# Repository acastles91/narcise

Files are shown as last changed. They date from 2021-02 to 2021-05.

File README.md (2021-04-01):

# Installation instructions

1. Download [Visual Studio Code](https://code.visualstudio.com/) and once that is done, install [PlatformIO](https://docs.platformio.org/en/latest/integration/ide/vscode.html#installation).
2. Open a terminal window and install *numpy*, a python library, by running the following command in the terminal:
`pip3 install numpy`
3. Clone this repository in a folder that you can remember, by typing the following command into the terminal:
`git clone https://github.com/acastles91/narcise/`
	* Navigate through folders using the command `cd`
4. In **Visual Studio Code** go to *File > Open Folder* and open the folder *narciseFromScratch* inside the *narcise* directory that you just cloned. This is where you will compile the code that will go into the microcontroller.
5. Navigate to the *narcise* folder with the file browser. Inside of it you will find a directory called *scriptGenerator*. Open the file *script* with **TextEdit**.
6. Edit the script. Each line represents a keyframe, which you define by first defining the *Timestamp* with the format *hh:mm:ss:fff*, where fff represents fractions of a second in milliseconds. After that comes the value of opacity of each layer as a percentage, with 100 being transparent and 0 being totally opaque. It is important that you keep this format consistent throughout the whole file. Make sure that you leave **no extra whitespace at the end of the file*
7. After saving the script, go back to *Visual Studio Code*, with the folder *narciseFromScratch* opened. Go to the terminal and type:
`cd ../scriptGenerator`
`python3 scriptGenerator.py 1 200 7`

	The argument `1` means that the script will be looped, `200` is the refresh rate (the bigger the value the slower and more "flickery" the piece will look) and `7` is a parameter that relates to the difference between minimal and maximal value. Play around with this last parameter to see differences in the response time of the dimming.

8. After the script is generated, connect the microcontroller to the computer using a USB cable capable of transfering data and upload the program.

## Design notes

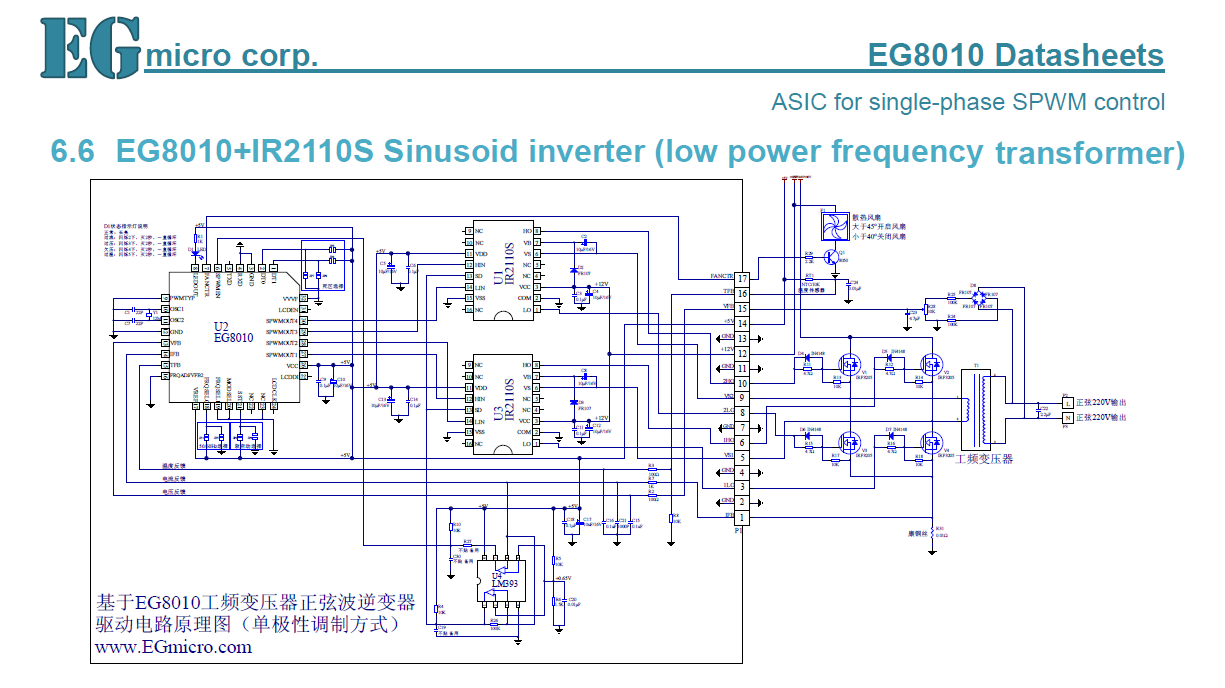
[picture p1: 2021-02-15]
EGS002-TechBuilder/Schematic, PCB Files & Datasheet/Schematics/Schematic.png

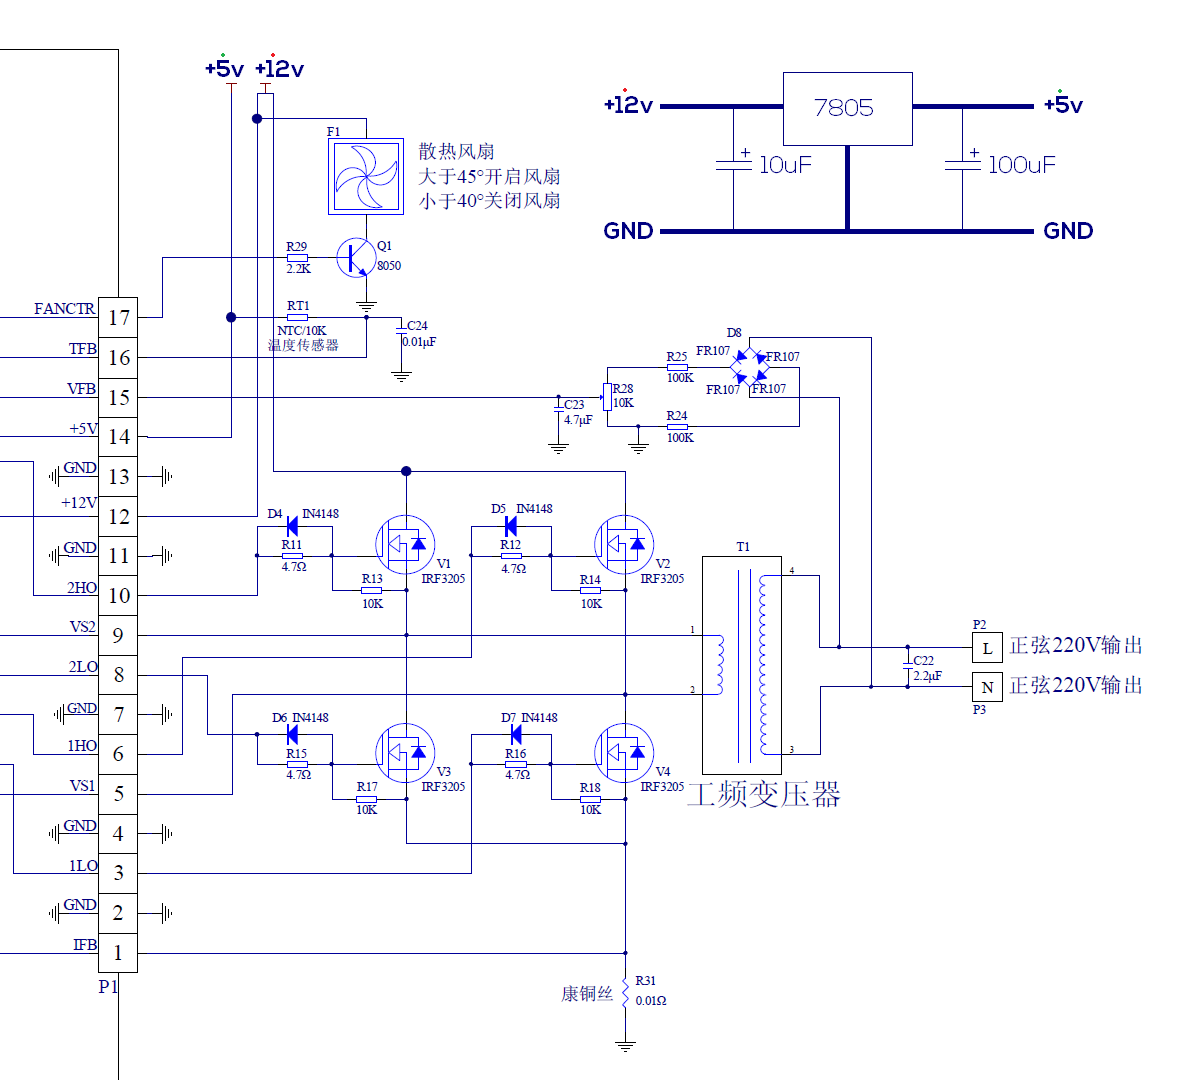
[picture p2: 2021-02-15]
EGS002-TechBuilder/Schematic, PCB Files & Datasheet/Schematics/Schematic (Close-up).png

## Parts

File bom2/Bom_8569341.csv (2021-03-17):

Manufacturer Part Number | Manufacturer | Digi-Key Part Number | Customer Reference | Reference Designator | Packaging | Part Status | Quantity | Unit Price | Extended Price | Quantity Available | Mfg Std Lead Time | Description | RoHS Status | Lead Free Status | REACH Status
2005280040 | Molex | WM20760CT-ND |  |  | Cut Tape (CT) | Active | 50 | 0,32900 | 16,45 € | 11305 | 12 Weeks | 1.0 FPC ZIF BTM CONT EMBT PKG 4C | ROHS3 Compliant | Lead free | REACH Unaffected
HRP-300N-24 | MEAN WELL USA Inc. | 1866-HRP-300N-24-ND |  |  | Box | Active | 1 | 76,68000 | 76,68 € | 5 | 11 Weeks | 300W SINGLE OUTPUT WITH PFC FUNC | Not Available | Not Available | Not Available
IRLZ44PBF | Vishay Siliconix | IRLZ44PBF-ND |  |  | Tube | Active | 7 | 2,15000 | 15,05 € | 611 | 8 Weeks | MOSFET N-CH 60V 50A TO220AB | ROHS3 Compliant | Lead free | Not Available
5-5530843-0 | TE Connectivity AMP Connectors | A31722-ND |  |  | Bulk | Active | 16 | 1,53500 | 24,56 € | 24454 | 5 Weeks | CONN CARDEDGE FEMALE 20POS 0.100 | RoHS Compliant | Lead free | Not Available
TMC5160A-TA-T | Trinamic Motion Control GmbH | 1460-TMC5160A-TA-TCT-ND |  |  | Cut Tape (CT) | Active | 4 | 5,63000 | 22,52 € | 20773 | 6 Weeks | IC MTR DRVR BIPOLAR 8-60V 48TQFP | ROHS3 Compliant | Not Available | Not Available

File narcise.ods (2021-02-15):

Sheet: Sheet1
Task | Hours
Development of an electronic schematic and ordering parts for testing | 10
Design of the module 3D CAD | 2
Design of the chassis 3D CAD | 3
Design of the light box 3D CAD | 3
Design of the frame 3D CAD | 2
Revision and correction of the design and ordering parts | 5
Testing schematic on breadboard | 4
Design of the module EDA | 2
Design of the chassis EDA | 3
Design of the light box EDA | 2
Order PCB from JLCPCB | 1
Make threads and finish laser cut parts | 5
Assembly and soldering of the PCB | 5
Assembly of the chassis and modules for inspection | 5
Assembly of the light box | 5
Correction of the PCB and order of the second version | 4
Correction of the enclosure and order of the second version | 3
Assembly and soldering of the PCB | 5
Assembly of the whole piece | 5
 | 74
 | Total | 2960

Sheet: Sheet2
Item | Quantity | Cost | Link
Old TV / Monitor
Laser cut parts
Electronic components
Laser Cutter
Wire stripper
Watch
Sweater

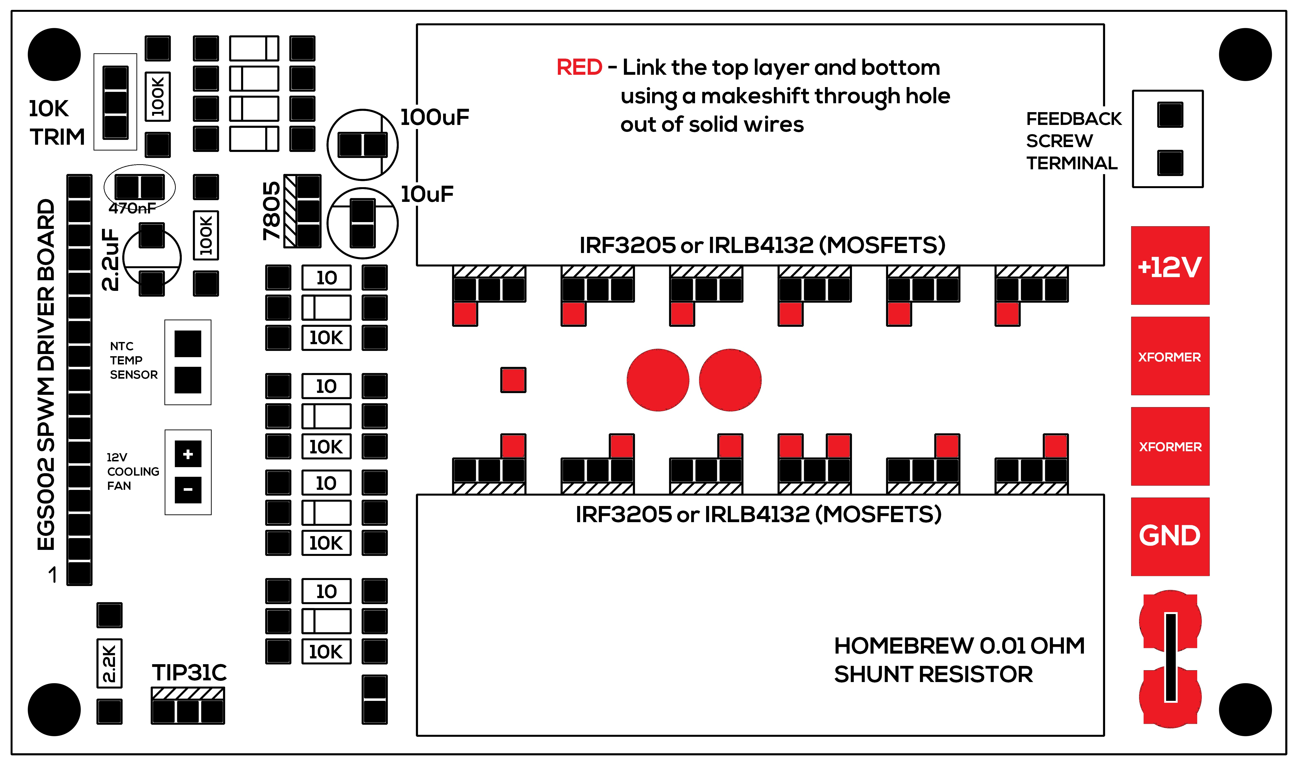
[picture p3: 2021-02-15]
EGS002-TechBuilder/Schematic, PCB Files & Datasheet/PCB Files/Parts Placement Diagram.jpg

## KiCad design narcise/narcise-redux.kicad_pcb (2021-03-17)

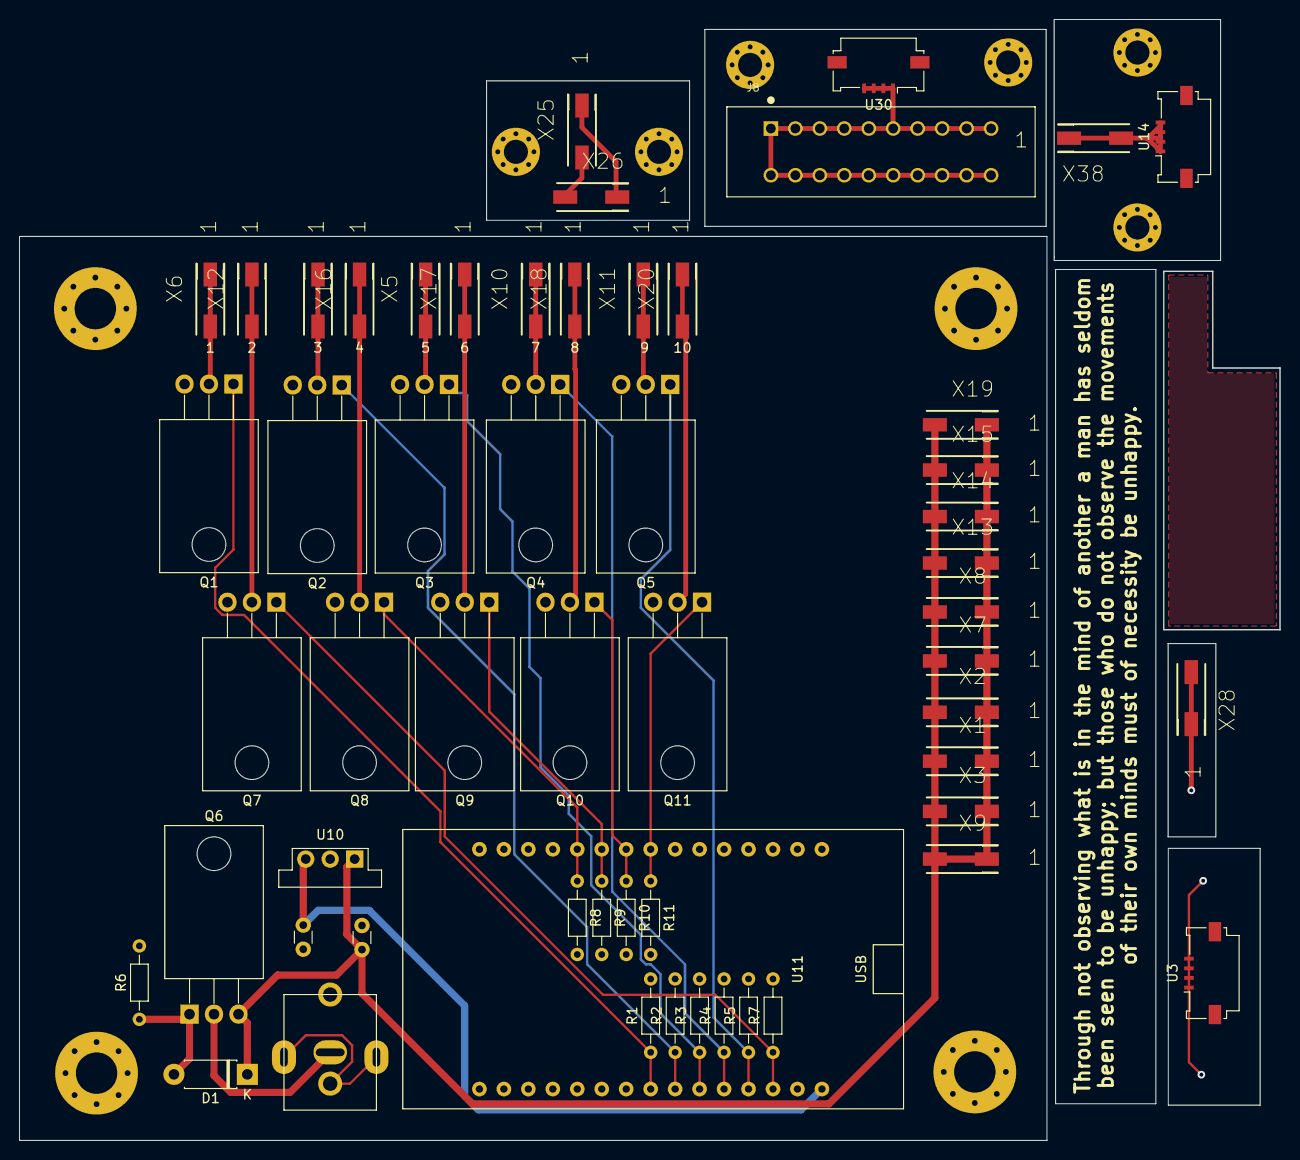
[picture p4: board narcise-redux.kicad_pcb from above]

Board: 2 copper layers, 130.9 x 116.4 mm, 56 parts (0 on the bottom side), 31 nets.

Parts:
D1: D_Zener-10V; D_DO-41_SOD81_P7.62mm_Horizontal
J8: 5-5530843-0; TE_5-5530843-0
Murata-Ceramic-Capacitor-50v1-22uF1, Murata-Ceramic-Capacitor-50v1-22uF2: C; C_Disc_D3.0mm_W1.6mm_P2.50mm
Q1, Q2, Q3, Q4, Q5, Q7, Q8, Q9, Q10, Q11: IRLZ44N-horizontal; TO-220-3_Horizontal_TabDown
Q6: IRF5305-Reverse-Polarity; TO-220-3_Horizontal_TabDown
R1, R2, R3, R4, R5, R7, R8, R9, R10, R11: R; R_Axial_DIN0204_L3.6mm_D1.6mm_P7.62mm_Horizontal
R6: 100K; R_Axial_DIN0204_L3.6mm_D1.6mm_P7.62mm_Horizontal
U3, U14: fpc-connector-mosfet-drain; Molex_200528-0040_1x04-1MP_P1.00mm_Horizontal
U10: OKI-78SR-5v; Converter_DCDC_muRata_OKI-78SR_Vertical
U11: ariadne-rescue_ESP32-WROOM-32D-ariadne; ESP32-DEVKIT
U21: POWER_CONNECTOR-DCJ250-20-B-K1-A; POWER_JACK_DCJ250-20-B-K1-A
U30: fpc-connector-VIN; Molex_200528-0040_1x04-1MP_P1.00mm_Horizontal
X1, X2, X3, X4, X5, X6, X7, X8, X9, X10, X11, X12, X13, X14, X15, X16, X17, X18, X19, X20, X25, X26, X28, X38: 2059-301_998-403; 998-403

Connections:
+5V: Murata-Ceramic-Capacitor-50v1-22uF2.1, U10.3, U11.15
+24V: D1.1, Murata-Ceramic-Capacitor-50v1-22uF1.1, Q6.3, U10.1, X1.L1.1, X1.L1.2, X2.L1.1, X2.L1.2, X3.L1.1, X3.L1.2, X7.L1.1, X7.L1.2, X8.L1.1, X8.L1.2, X9.L1.1, X9.L1.2, X13.L1.1, X13.L1.2, X14.L1.1, X14.L1.2, X15.L1.1, X15.L1.2, X19.L1.1, X19.L1.2
unnamed: D1.2, Q6.1, R6.1
unnamed: J8.1, J8.2, J8.3, J8.4, J8.5, J8.6, J8.7, J8.8, J8.9, J8.10, J8.11, J8.12, J8.13, J8.14, J8.15, J8.16, J8.17, J8.18, J8.19, J8.20, U30.1, U30.2, U30.3, U30.4
unnamed: Q1.2, X6.L1.1, X6.L1.2
unnamed: Q2.2, X4.L1.1, X4.L1.2
unnamed: Q3.2, X5.L1.1, X5.L1.2
unnamed: Q4.2, X10.L1.1, X10.L1.2
unnamed: Q5.2, X11.L1.1, X11.L1.2
unnamed: Q7.2, X12.L1.1, X12.L1.2
unnamed: Q8.2, X16.L1.1, X16.L1.2
unnamed: Q9.2, X17.L1.1, X17.L1.2
unnamed: Q10.2, X18.L1.1, X18.L1.2
unnamed: Q11.2, X20.L1.1, X20.L1.2
unnamed: U3.1, U3.2, U3.3, U3.4
unnamed: U14.1, U14.2, U14.3, U14.4, X38.L1.1, X38.L1.2
unnamed: X25.L1.1, X26.L1.1
unnamed: X25.L1.2, X26.L1.2
unnamed: X28.L1.1, X28.L1.2
POWER-IN+: Q6.2, U21.1
POWER-IN-: Murata-Ceramic-Capacitor-50v1-22uF1.2, Murata-Ceramic-Capacitor-50v1-22uF2.2, Q1.3, Q2.3, Q3.3, Q4.3, Q5.3, Q7.3, Q8.3, Q9.3, Q10.3, Q11.3, R1.2, R2.2, R3.2, R4.2, R5.2, R6.2, R7.2, R8.2, R9.2, R10.2, R11.2, U10.2, U11.14, U11.17, U21.2
sheet1: Q1.1, R1.1, U11.8
sheet2: Q2.1, R2.1, U11.9
sheet3: Q3.1, R3.1, U11.10
sheet4: Q4.1, R4.1, U11.11
sheet5: Q5.1, R5.1, U11.12
sheet6: Q7.1, R7.1, U11.13
sheet7: Q8.1, R8.1, U11.26
sheet8: Q9.1, R9.1, U11.25
sheet9: Q10.1, R10.1, U11.24
sheet10: Q11.1, R11.1, U11.23

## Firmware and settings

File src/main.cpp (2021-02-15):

// /*********
//   Rui Santos
//   Complete project details at https://RandomNerdTutorials.com/vs-code-platformio-ide-esp32-esp8266-arduino/
// *********/

// #include <Arduino.h>

// // const int smallDim = 33;
// // const int dim4 = 27;
// // const int dim5 = 26;
// // const int bigDim = 32;
// // const int nilsPwm = 35;
// // const int fanPwm = 34;
// // const int sw4 = 25;
// // const int sw3 = 26;
// // const int sw2 = 27;
// // const int sw1 = 14;
// // const int button1 = 17;
// // const int button2 = 16;
// // const int led1 = 4;
// // const int led2 = 2;

// const int pwm = 26;
// const int zc = 25;

// const int freq = 200;
// const int ledChannel = 3;
// const int resolution = 10;
// const int fanChannel = 4;


// void setup() {
//   // put your setup code here, to run once:
//   Serial.begin(115200);
//   pinMode(dim4, OUTPUT);
//   pinMode(dim5, OUTPUT);
//   ledcSetup(ledChannel, freq, resolution);
//   ledcSetup(fanChannel, freq, resolution);
//   //ledcAttachPin(fanPwm, ledChannel);
//   ledcAttachPin(dim5, ledChannel);
//   }

// void loop() {

//   //ledcWrite(ledChannel, 0);
//   // put your main code here, to run repeatedly:

//   //-----DIM!!!!!
// for(int dutyCycle = 0; dutyCycle <= 1023; dutyCycle+= 2){   
//     // changing the LED brightness with PWM
//     //ledcWrite(fanChannel, dutyCycle);
//     ledcWrite(ledChannel, dutyCycle);
//     delay(15);
//     }

//   for(int dutyCycle = 1023; dutyCycle >= 0; dutyCycle-= 2){
//     // changing the LED brightness with PWM
//     //ledcWrite(fanChannel, dutyCycle);
//     ledcWrite(ledChannel, dutyCycle);   
//     delay(15);
//   }

//     //-----DIM!!!!!


// //ledcWrite(ledChannel, 255);

// //digitalWrite(led1, HIGH);
// // if(digitalRead(sw1)){
// //   digitalWrite(led1, HIGH);

// // }
// // else{
// //   digitalWrite(led1, LOW);
// // }

// }

<#include <Arduino.h>
#include "../github-example/hw_timer.h"          
const byte zcPin = 12;
const byte pwmPin = 13;  >

byte fade = 1;
byte state = 1;
byte tarBrightness = 255;
byte curBrightness = 0;
byte zcState = 0; // 0 = ready; 1 = processing;
void dimTimerISR() {
    if (fade == 1) {
      if (curBrightness > tarBrightness || (state == 0 && curBrightness > 0)) {
        --curBrightness;
      }
      else if (curBrightness < tarBrightness && state == 1 && curBrightness < 255) {
        ++curBrightness;
      }
    }
    else {
      if (state == 1) {
        curBrightness = tarBrightness;
      }
      else {
        curBrightness = 0;
      }
    }
    
    if (curBrightness == 0) {
      state = 0;
      digitalWrite(pwmPin, 0);
    }
    else if (curBrightness == 255) {
      state = 1;
      digitalWrite(pwmPin, 1);
    }
    else {
      digitalWrite(pwmPin, 1);
    }
    
    zcState = 0;
}

void zcDetectISR() {
  if (zcState == 0) {
    zcState = 1;
  
    if (curBrightness < 255 && curBrightness > 0) {
      digitalWrite(pwmPin, 0);
      
      int dimDelay = 30 * (255 - curBrightness) + 400;//400
      hw_timer_arm(dimDelay);
    }
  }
}
void setup() {
  Serial.begin(115200);   
  pinMode(zcPin, INPUT_PULLUP);
  pinMode(pwmPin, OUTPUT);
  attachInterrupt(zcPin, zcDetectISR, RISING);    // Attach an Interupt to Pin 2 (interupt 0) for Zero Cross Detection
  hw_timer_init(NMI_SOURCE, 0);
  hw_timer_set_func(dimTimerISR);
}

void loop() {
  // put your main code here, to run repeatedly:
    if (Serial.available()){
        int val = Serial.parseInt();
        if (val>0){
          tarBrightness =val;
          Serial.println(tarBrightness);
        }
        
    }
}

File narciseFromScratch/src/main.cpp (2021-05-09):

#include <iostream>
#include <vector>
#include <RBDdimmer.h>
#include "main.h"
#include <analogWrite.h>
#include <stdlib.h>
//#include "esp32/RBDmcuESP32.h"
//#include "scriptTestTest.h"


//#define USE_SERIAL  SerialUSB //Serial for boards whit USB serial port
#define USE_SERIAL Serial
//#define outputPin  12
//#define zerocross  5 // for boards with CHANGEBLE input pins

//PINOUT

#define pwm1 27
#define pwm2 27
#define zc1 26
#define zc2 27
#define dac1 25
#define dac2 26
#define button 5

#define ch1 25  //not ok
#define ch2 13  //ok
#define ch3 26  //ok
#define ch4 21  //ok
#define ch5 27  //ok
#define ch6 19  //ok
#define ch7 14  //not ok
#define ch8 18  //ok
#define ch9 12  //ok
#define ch10  5 //ok

#define TIMER
//#define TROUBLE

std::vector<int> layers {ch1, ch2, ch3, ch4, ch5, ch6, ch7, ch8, ch9, ch10};
std::vector<int> channels {1, 2, 3, 4, 5, 6, 7, 8, 9, 10};

const int freq = 500;
const int ledChannel = 0;
const int resolution = 8;

int channelA = 12;
int channelB = 14;
int period = 400;
bool fullDim;
int poti = 35;
int brightness = 0;
int maxIndex;
volatile int indexBrightness = 0;
volatile bool niceFlag = false;

volatile int interruptCounter;
volatile bool channelBtrigger;
volatile bool waitBool;
volatile bool tickBool;

int layersSize = (int)layers.size();

int totalInterruptCounter;

hw_timer_t * timer = NULL;
hw_timer_t * timer2 = NULL;

portMUX_TYPE timerMux = portMUX_INITIALIZER_UNLOCKED;

void boolChange(){
  portENTER_CRITICAL(&timerMux);
  waitBool = true;
  portEXIT_CRITICAL(&timerMux);
}

void IRAM_ATTR waitTimerA(){
  portENTER_CRITICAL_ISR(&timerMux);
  if (waitBool){
    digitalWrite(channelB, !digitalRead(channelA));
    waitBool = false;
  }
  portEXIT_CRITICAL_ISR(&timerMux);
}

void IRAM_ATTR triggerTimerA(){
  portENTER_CRITICAL_ISR(&timerMux);
  digitalWrite(channelB, !digitalRead(channelA));
  portEXIT_CRITICAL_ISR(&timerMux);
}

void IRAM_ATTR onTimerA(){
  portENTER_CRITICAL_ISR(&timerMux);
  digitalWrite(channelA, !digitalRead(channelA));
  timerAttachInterrupt(timer2, waitTimerA, true);
  timerAlarmWrite(timer2, (period / 4), true);
  timerAlarmEnable(timer2);
  portEXIT_CRITICAL_ISR(&timerMux);
}


void IRAM_ATTR waitTimerB(){
  portENTER_CRITICAL_ISR(&timerMux);
  if (waitBool){
    digitalWrite(channelB, !digitalRead(channelB));
    waitBool = false;
  }
  portEXIT_CRITICAL_ISR(&timerMux);
}

void IRAM_ATTR triggerTimerB(){
  portENTER_CRITICAL_ISR(&timerMux);
  digitalWrite(channelA, !digitalRead(channelB));
  portEXIT_CRITICAL_ISR(&timerMux);
}

void IRAM_ATTR onTimerB(){
  portENTER_CRITICAL_ISR(&timerMux);
  digitalWrite(channelB, !digitalRead(channelB));
  timerAttachInterrupt(timer2, waitTimerB, true);
  timerAlarmWrite(timer2, (period / 4), true);
  timerAlarmEnable(timer2);
  portEXIT_CRITICAL_ISR(&timerMux);
}

void IRAM_ATTR finalTrigger(){
  portENTER_CRITICAL_ISR(&timerMux);
  for (int i = 0; i < layers.size(); i ++){
    //ledcWrite(channels[i], finalLines[indexBrightness][i]); original, for some reason stopped working
    analogWrite(channels[i], finalLines[indexBrightness][i]);
    }
    indexBrightness ++;
    niceFlag = true;
    
  portEXIT_CRITICAL_ISR(&timerMux);
}



void interruptChannelB(){

  // portENTER_CRITICAL(&timerMux);
  // channelBtrigger = false;
  // portEXIT_CRITICAL(&timerMux);

  // timerAttachInterrupt(timer2, triggerTimer, true);
  // timerAlarmWrite(timer2, (period / 2), false);
  // timerAlarmEnable(timer2);
}

void tickA(){

  tickBool = true;
  timer = timerBegin(0, 80, true);
  timer2 = timerBegin(1, 80, true);
  // attachInterrupt(channelA, boolChange, CHANGE);
  // timerAttachInterrupt(timer, onTimerA, true);
  // timerAlarmWrite(timer, (period / 2), true);
  // timerAlarmEnable(timer);
  tickBool = false;

}

void tickB(){
  tickBool = true;
  attachInterrupt(channelB, boolChange, CHANGE);
  timerAttachInterrupt(timer, onTimerB, true);
  timerAlarmWrite(timer, (period / 2), true);
  timerAlarmEnable(timer);
  tickBool = false;
}

void tickOff(){
  detachInterrupt(channelB);
  detachInterrupt(channelA);
  timerStop(timer);
  timerStop(timer2);

}

void toggleSwitch(){
digitalWrite(button, !digitalRead(button));

}

void stupid(int periodArg, int durationArg, int channelAarg, int channelBarg){

  for(int i = 0; i > durationArg; i++){
    digitalWrite(channelAarg, HIGH);
    delayMicroseconds(periodArg/4);
    digitalWrite(channelBarg, digitalRead(channelAarg));
    delayMicroseconds(periodArg/4);
    digitalWrite(channelAarg, !digitalRead(channelAarg));
    delayMicroseconds(periodArg/4);
    digitalWrite(channelBarg, !digitalRead(channelBarg));
    delay(1000);
  }
}


void setup(){

  #include "codeFile"

  Serial.begin(115200);

  for (int i = 0; i < layers.size(); i++){
    pinMode(layers[i], OUTPUT);
    //ledcSetup(channels[i], 100, resolution);
    ledcSetup(channels[i], refreshRate, resolution);
    ledcAttachPin(layers[i], channels[i]);
  }

  #ifdef TROUBLE

  ledcSetup(1, 100, resolution);
  ledcAttachPin(ch1, ch1);

  #endif


  #ifdef  TIMER

    timer = timerBegin(0, 80, true);
    timerAttachInterrupt(timer, &finalTrigger, true);
    timerAlarmWrite(timer, refreshRate * 1000, true);
    timerAlarmEnable(timer);

  #endif

  pinMode(channelA, OUTPUT);
  pinMode(channelB, OUTPUT);
  pinMode(button, OUTPUT);

  analogWriteFrequency(refreshRate);
  analogWriteResolution(8);

  tickBool = false;
  fullDim = false;
  //attachInterrupt(button, tick, HIGH);

  digitalWrite(button, HIGH);

  digitalWrite(button, !digitalRead(button));
  
  maxIndex = (int)finalLines.size();


}

void loop(){

  //ledcWrite(channels[1], 1);

  // for (int i = 0; i < 255; i++){
  //   analogWrite(layers[1], i);
    
  //   //ledcWrite(channels[1], i);
  //   Serial.println(i);
  //   delay(2000);
  // }

#ifdef TROUBLE

ledcWrite(ch1, 255);
delay(1000);
ledcWrite(ch1, 0);
delay(1000);

#endif


#ifdef TIMER

  if (niceFlag == true){
    Serial.println(indexBrightness);
    //Serial.println(maxIndex);
    niceFlag = false;
  }

  if (indexBrightness == maxIndex){

    if (repeatBool){
      portENTER_CRITICAL(&timerMux);
      indexBrightness = 0;
      portEXIT_CRITICAL(&timerMux);
    }
    else{

      timerDetachInterrupt(timer);
    }
  }

#endif

}

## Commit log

2021-03-05 Before moving to Desktop
    [narcise.sch]
2021-03-17 After PCB order
    [Bom_8569341.csv, file6043A646.sch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]
2021-05-09 changed ledcWrite for analogWrite
